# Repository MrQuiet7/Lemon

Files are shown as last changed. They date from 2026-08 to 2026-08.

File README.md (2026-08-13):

<p align="center">
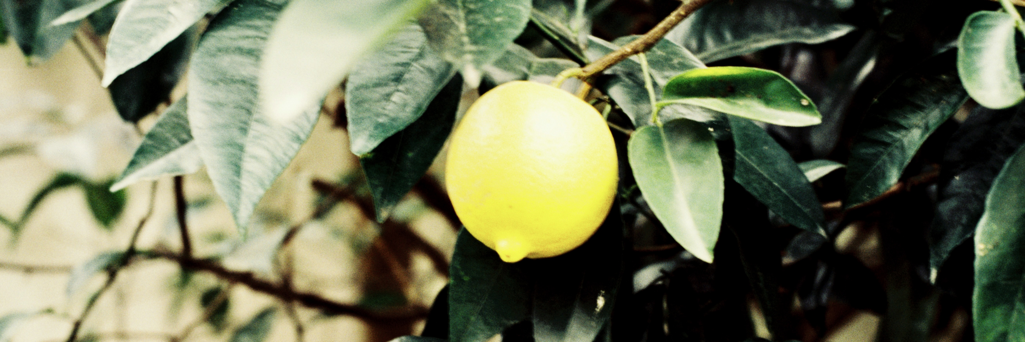
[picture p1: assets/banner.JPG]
‌banner
  
</p>

# Lemon! 🍋

### Stereo 20-LED VU Meter

> When life gives you a lemon, plug your music into it.

### Lemon is a compact stereo VU meter built around two LM3915N-1 LED bar-graph driver ICs.

### The design provides 10 LED levels for each stereo channel, giving a total of 20 LEDs. It is intended to be used as a standalone audio visualizer or integrated into an amplifier.

## Features

* Stereo audio level display
* 2× LM3915N-1
* 20× rectangular LEDs
* 10 levels per channel
* Independent sensitivity adjustment for left and right channels
* 3.5 mm stereo audio input/output
* Adjustable DOT / BAR display mode
* 15–25 V DC supply
* Designed for integration into an audio amplifier
* Two-layer PCB with large GND copper zones

## Design

* Lemon is based on the LED VU meter circuit published by Elliott Sound Products.

* The original circuit uses an LM3915 to drive ten LEDs according to the level of an incoming audio signal. Lemon uses two identical sections for the left and right channels.

* Each channel has its own sensitivity adjustment, allowing the two VU meters to be calibrated independently.

## Signal Flow

* The audio signal is passed through the board while each stereo channel is sampled by its respective LM3915 section for visual level indication.

## Power

* Lemon is designed for a 15–25 V DC supply.

* The PCB uses a single positive supply and ground connection. The LED supply path and LM3915 supply path are separated on the board according to the original circuit.

* The EARTH connection is kept separate from the main GND plane through the original 10 Ω connection, allowing the board to be integrated into a larger amplifier system without unnecessarily tying the two together.

## PCB

#### The PCB was designed in KiCad with a focus on:

<p align="center">
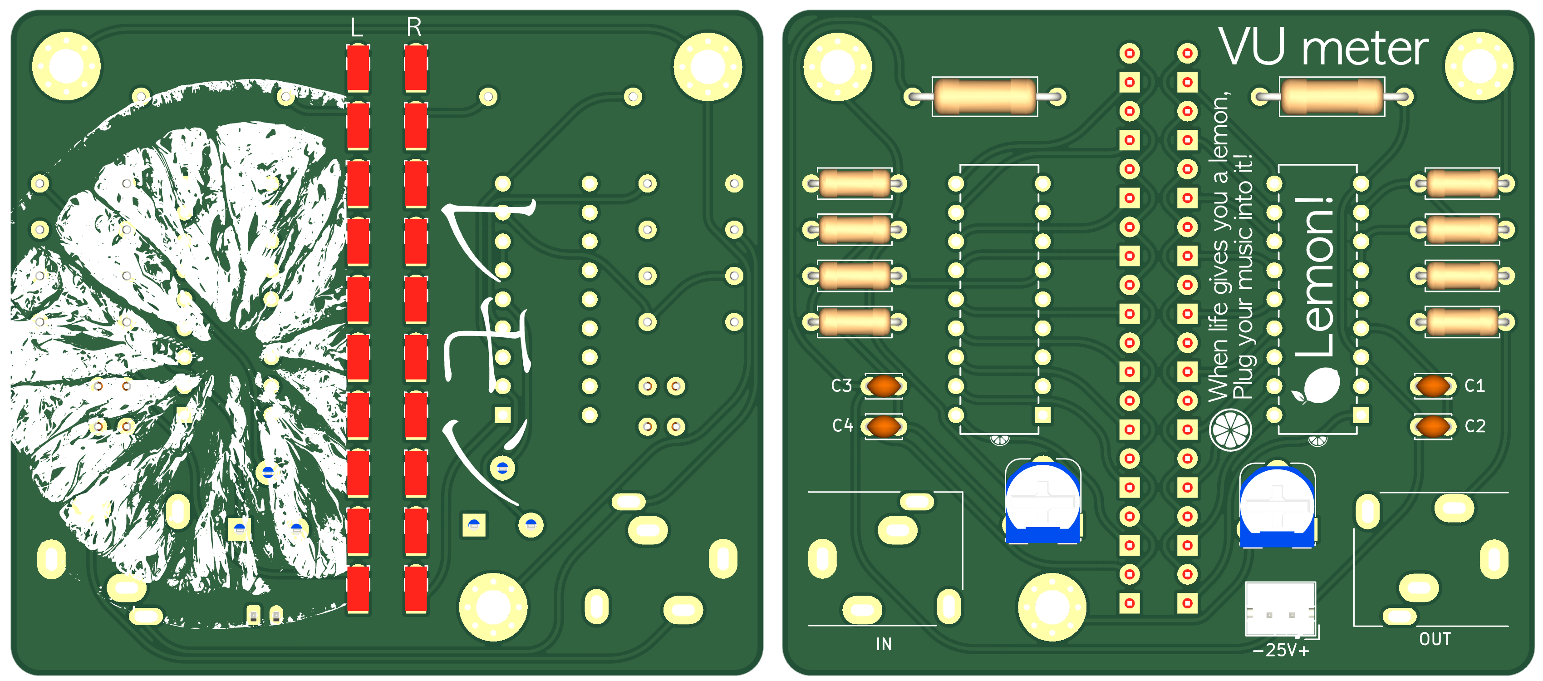
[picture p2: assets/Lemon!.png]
  
</p>

* Clean stereo symmetry
* Short and organized signal paths
* Large GND copper zones
* Easy component identification
* Through-hole construction
* Simple integration into an amplifier enclosure

### The two rows of LEDs form the main visual element of the board, with the LM3915 circuits and adjustment controls positioned behind them.

* Components

### Quantity	Component
* 2	x LM3915N-1
* 20 x	Rectangular LEDs
* 2	x 50 kΩ potentiometers
* 2	x 3.5 mm stereo TRS jacks
* 2	x 82 Ω / 0.5 W resistors
* 2	x 1.2 kΩ resistors
* 2 x	2.2 kΩ resistors
* 2	x 10 kΩ resistors
* 2	x 10 Ω resistors
* 4	x 100 nF capacitors

### Component values and quantities should be verified against the final schematic and BOM before assembly.

## Project Status

* The VU meter circuit is based on the design published by [Elliott Sound Products](https://sound-au.com/project60.htm).

* Lemon is an independent PCB implementation and stereo adaptation of the circuit, with a custom PCB layout, mechanical arrangement, and visual design.

## License

#### GNU General Public License v3.0

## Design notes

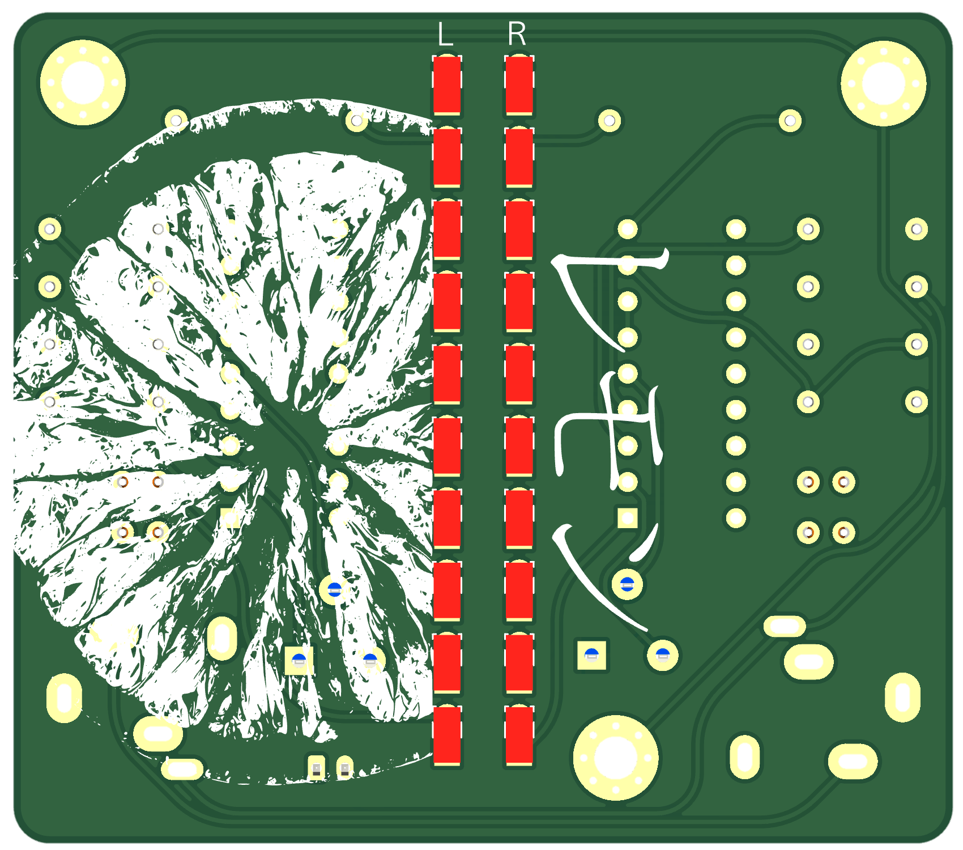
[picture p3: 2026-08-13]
assets/Back.png

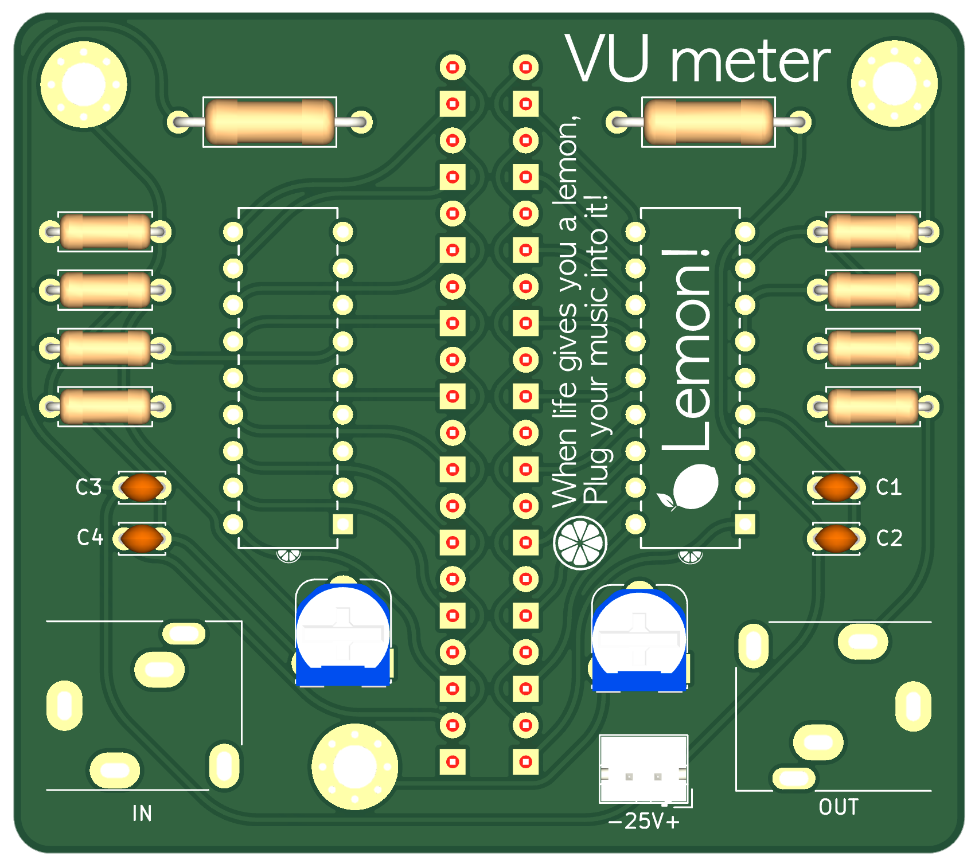
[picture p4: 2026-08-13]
assets/Front.png

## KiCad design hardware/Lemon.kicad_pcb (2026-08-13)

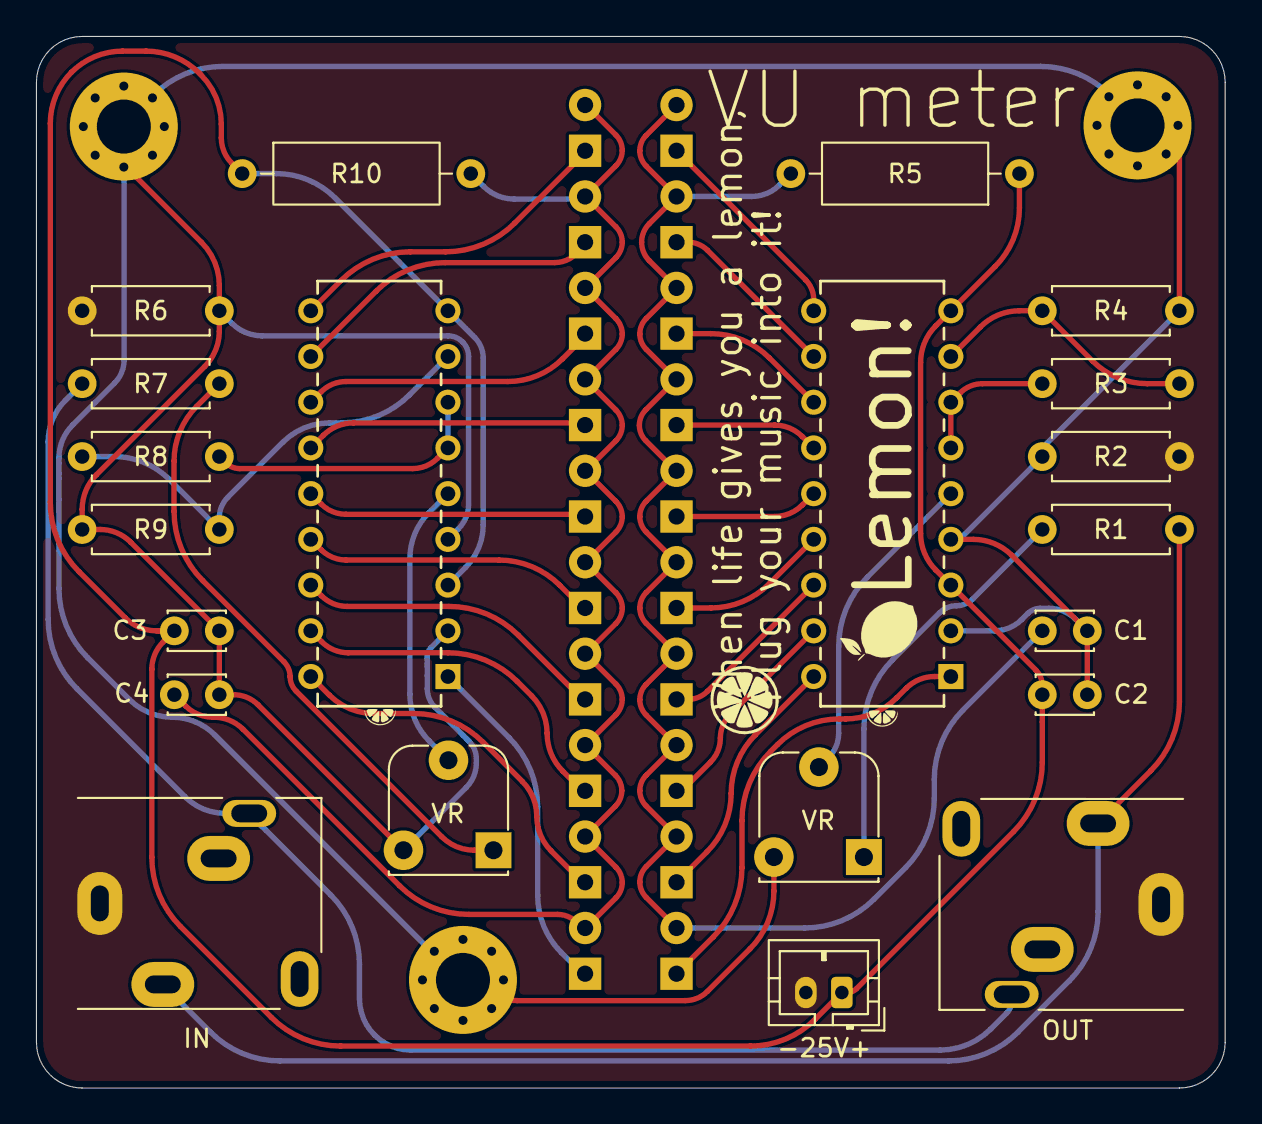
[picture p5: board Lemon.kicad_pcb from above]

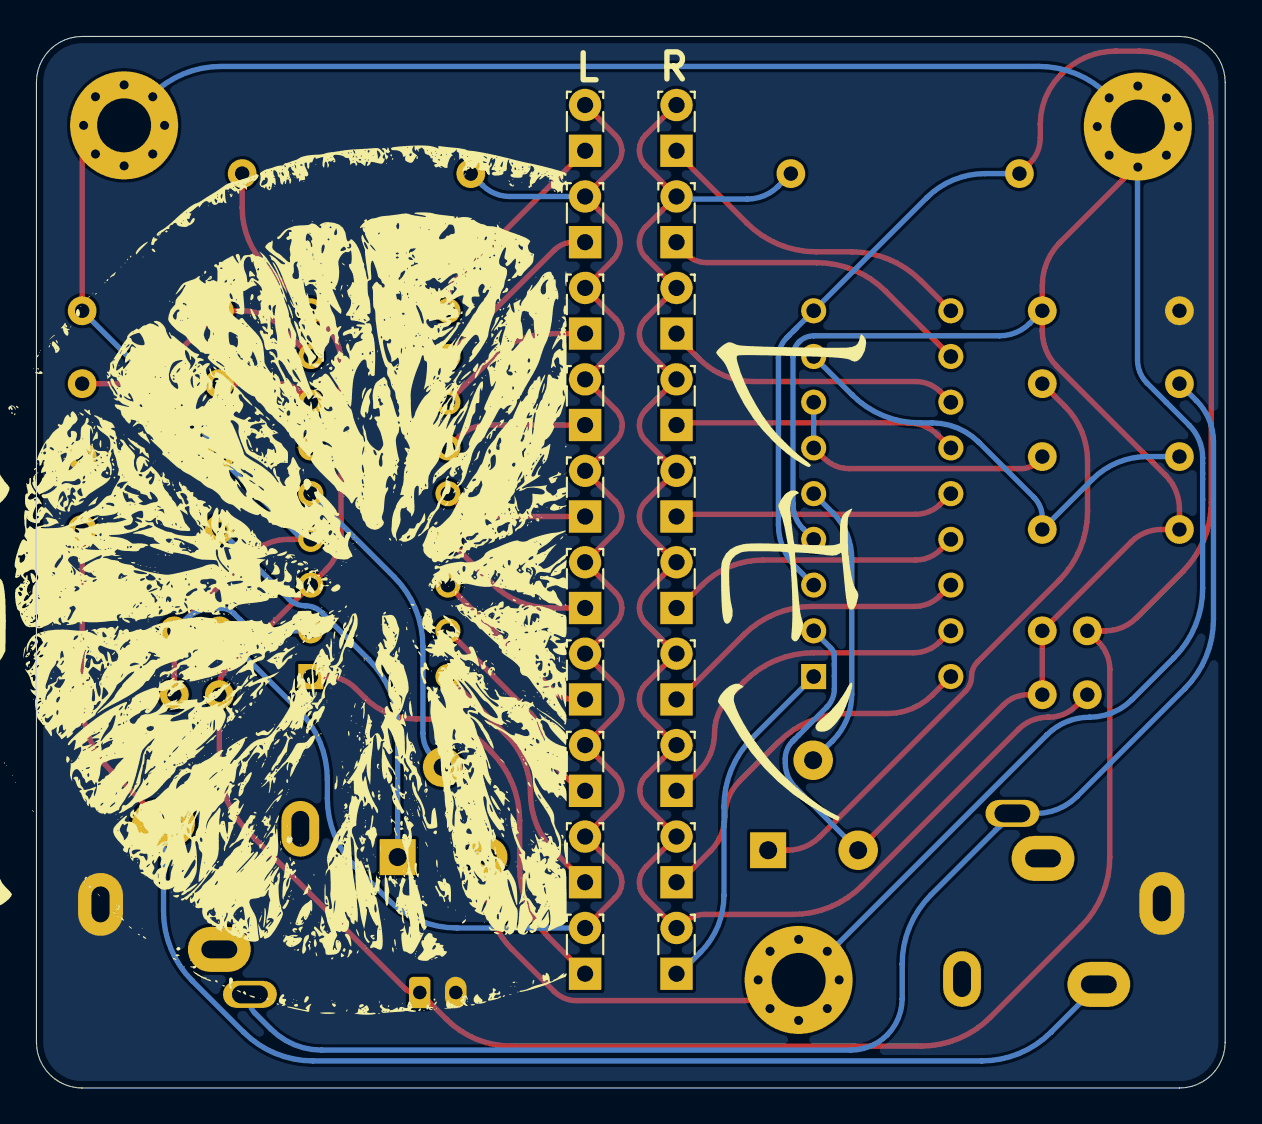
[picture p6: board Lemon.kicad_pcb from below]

Board: 2 copper layers, 66.0 x 58.4 mm, 41 parts (20 on the bottom side), 35 nets.

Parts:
-25V+: 25v; JST_PH_B2B-PH-K_1x02_P2.00mm_Vertical
C1, C2, C3, C4: 100n; C_Disc_D3.0mm_W2.0mm_P2.50mm
D1, D2, D3, D4, D5, D6, D7, D8, D9, D10, D11, D12, D13, D14, D15, D16, D17, D18, D19, D20: LED; LED_Rectangular_W3.9mm_H1.9mm
IN: AudioJack3_SwitchTR; Jack_3.5mm_CUI_SJ1-3515N_Horizontal
OUT: AudioJack3_SwitchTR; Jack_3.5mm_CUI_SJ1-3515N_Horizontal
R1, R2, R6, R7: 10k; R_Axial_DIN0207_L6.3mm_D2.5mm_P7.62mm_Horizontal
R3, R8: 1.2k; R_Axial_DIN0207_L6.3mm_D2.5mm_P7.62mm_Horizontal
R4, R9: 2.2k; R_Axial_DIN0207_L6.3mm_D2.5mm_P7.62mm_Horizontal
R5, R10: 82R0.5W; R_Axial_DIN0309_L9.0mm_D3.2mm_P12.70mm_Horizontal
U1, U2: LM3915N-1; NA18A_TEX
VR: 50k; Potentiometer_RM065
VR#2: 50k; Potentiometer_RM065

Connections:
/6: R3.2, U1.6 (DIVIDER(HIGH_END)), U1.7 (REFERENCE_OUTPUT)
/8: R3.1, R4.2, U1.8 (REFERENCE_ADJUST)
/GND: -25V+.2, IN.S, OUT.S, R2.1, R6.1
/L: IN.T, OUT.T, R1.1
/LED1: D1.1 (K), U1.1 (LED_NO_1)
/LED2: D2.1 (K), U1.18 (LED_NO_2)
/LED3: D3.1 (K), U1.17 (LED_NO_3)
/LED4: D4.1 (K), U1.16 (LED_NO_4)
/LED5: D5.1 (K), U1.15 (LED_NO_5)
/LED6: D6.1 (K), U1.14 (LED_NO_6)
/LED7: D7.1 (K), U1.13 (LED_NO_7)
/LED8: D8.1 (K), U1.12 (LED_NO_8)
/LED9: D9.1 (K), U1.11 (LED_NO_9)
/LED10: D10.1 (K), U1.10 (LED_NO_10)
/LED11: D11.1 (K), U2.1 (LED_NO_1)
/LED12: D12.1 (K), U2.18 (LED_NO_2)
/LED13: D13.1 (K), U2.17 (LED_NO_3)
/LED14: D14.1 (K), U2.16 (LED_NO_4)
/LED15: D15.1 (K), U2.15 (LED_NO_5)
/LED16: D16.1 (K), U2.14 (LED_NO_6)
/LED17: D17.1 (K), U2.13 (LED_NO_7)
/LED18: D18.1 (K), U2.12 (LED_NO_8)
/LED19: D19.1 (K), U2.11 (LED_NO_9)
/LED20: D20.1 (K), U2.10 (LED_NO_10)
/Lin: U2.5 (SIGNAL_INPUT), VR#2.2
/R: IN.R, OUT.R, R7.1
/Rin: U1.5 (SIGNAL_INPUT), VR.2
/VCC: -25V+.1, C2.1, C3.1, R5.1, R10.1, U1.3 (V+), U1.9 (MODE_SELECT), U2.3 (V+), U2.9 (MODE_SELECT)
/g: R8.1, R9.2, U2.8 (REFERENCE_ADJUST)
/s: R8.2, U2.6 (DIVIDER(HIGH_END)), U2.7 (REFERENCE_OUTPUT)
Earth: C1.2, C2.2, C3.2, C4.2, R2.2, R4.1, R6.2, R9.1, U1.2 (V-), U1.4 (DIVIDER(LOW_END)), U2.2 (V-), U2.4 (DIVIDER(LOW_END)), VR.3, VR#2.3
unnamed: C1.1, D1.2 (A), D2.2 (A), D3.2 (A), D4.2 (A), D5.2 (A), D6.2 (A), D7.2 (A), D8.2 (A), D9.2 (A), D10.2 (A), R5.2
unnamed: C4.1, D11.2 (A), D12.2 (A), D13.2 (A), D14.2 (A), D15.2 (A), D16.2 (A), D17.2 (A), D18.2 (A), D19.2 (A), D20.2 (A), R10.2
unnamed: R1.2, VR.1
unnamed: R7.2, VR#2.1
